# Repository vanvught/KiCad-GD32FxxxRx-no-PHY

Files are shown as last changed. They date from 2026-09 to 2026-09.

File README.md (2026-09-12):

[PayPal.Me Donate](https://paypal.me/AvanVught?locale.x=nl_NL)
-----------

# KiCad GD32F103R GD32F107R GD32F207R GD32F303R GD32F407R development board

This board can be used with the `GD32F103Rx`,  `GD32F303Rx` and the `GD32F107Rx` , `GD32F207Rx`, `GD32F407Rx` (Ethernet) MCU's. 

Please note that the crystal for the `GD32F107Rx`, `GD32F207Rx` and the `GD32F407Rx` is `25MHz` and the crystal for the `GD32F103Rx` and the  `GD32F303Rx` is `8MHz`.

The 2x13 header is pin compatible with the Orange Pi Zero and Raspberry Pi boards. 

Note: The BOM is for the GD32F407RE.
ToDo: Add information for other supported MCU's.

Details -> [https://www.gd32-dmx.org/dev-board.html](https://www.gd32-dmx.org/dev-board.html)

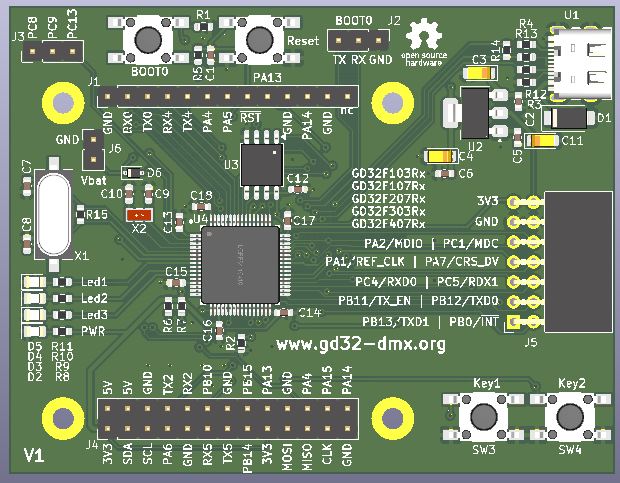
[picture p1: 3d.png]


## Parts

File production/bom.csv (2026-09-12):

Designator | Footprint | Quantity | Value | LCSC Part #
C1, C12, C13, C14, C15, C16, C17, C18, C2, C5, C6 | 0603 | 11 | 100n | C14663
C10, C9 | 0603 | 2 | 12pF | C38523
C11, C3, C4 | CP_EIA-3216-18_Kemet-A | 3 | 10uF | C7171
C7, C8 | 0603 | 2 | 20pF | C1648
D1 | D_SMA | 1 | SMAJ5.0A | C113952
D2, D3, D4, D5 | 0805 | 4 | LED | C2297
D6 | D_SOD-323 | 1 | 1N5819 | C48997863
R1, R2, R5 | 0603 | 3 | 10K | C25804
R10, R8, R9 | 0603 | 3 | 1K5 | C22975
R11 | 0603 | 1 | 1K5 | C22843
R12, R13 | 0603 | 2 | 22 | C23345
R15 | 0603 | 1 | 1M | C22935
R3, R4 | 0603 | 2 | 5K1 | C23186
R6, R7 | 0603 | 2 | 4K7 | C23162
SW1 | KEY-SMD_4P-L6.0-W6.0-P4.50-LS9.0 | 1 | BOOT0 | C221880
SW2 | KEY-SMD_4P-L6.0-W6.0-P4.50-LS9.0 | 1 | RESET | C221880
SW3 | KEY-SMD_4P-L6.0-W6.0-P4.50-LS9.0 | 1 | KEY1 | C221880
SW4 | KEY-SMD_4P-L6.0-W6.0-P4.50-LS9.0 | 1 | KEY2 | C221880
U1 | USB-C-SMD_G-SWITCH_GT-USB-7010ASV | 1 | GT-USB-7010ASV | C2988369
U2 | SOT-223-3_TabPin2 | 1 | AMS1117-3.3
U3 | SOIC-8_5.3x5.3mm_P1.27mm | 1 | W25Q128JVS | C97521
U4 | LQFP-64_L10.0-W10.0-P0.50-LS12.0-BL | 1 | GD32F407RET6 | C2688748
X1 | HC-49S_L11.4-W4.8 | 1 | 25Mhz | C14872
X2 | FC-135R_L3.2-W1.5 | 1 | 32.768kHz | C32346

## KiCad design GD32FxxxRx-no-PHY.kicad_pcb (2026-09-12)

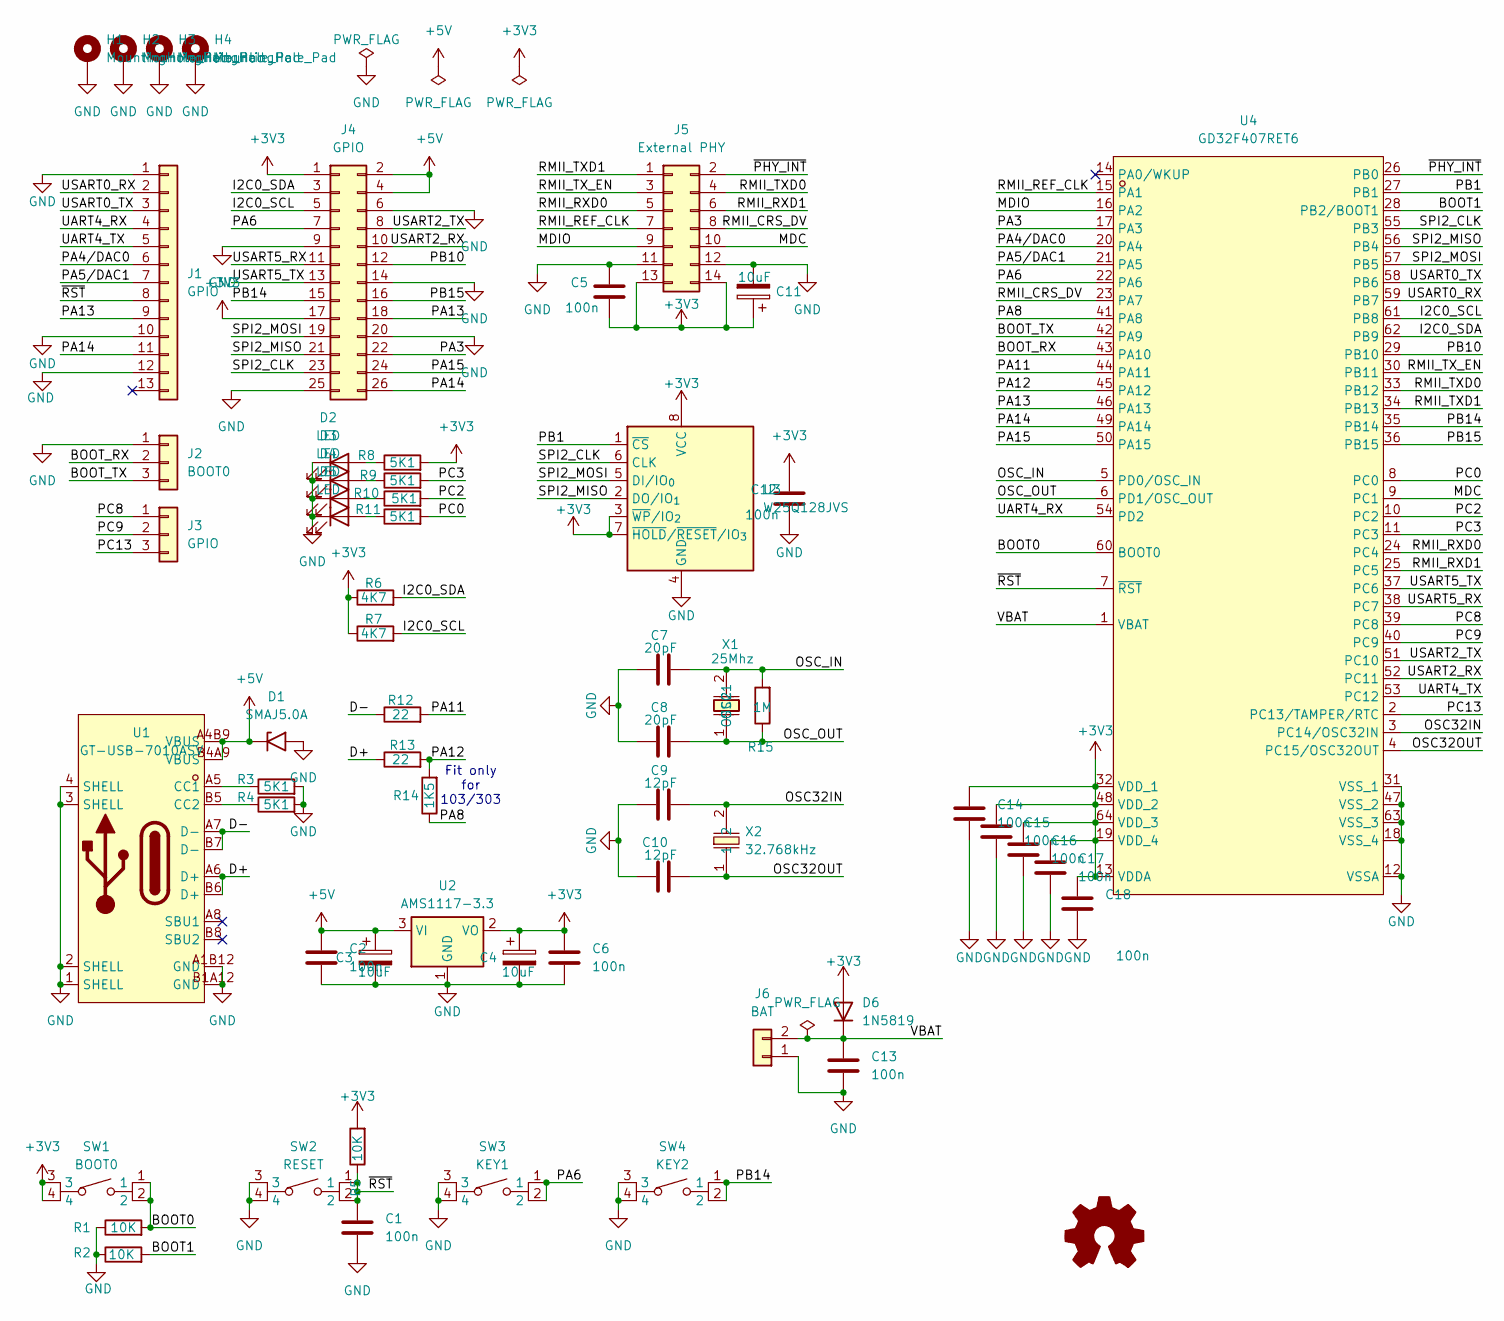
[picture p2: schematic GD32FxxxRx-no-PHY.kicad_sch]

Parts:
C1, C2, C5, C6, C12, C13, C14, C15, C16, C17, C18: 100n; C_0603_1608Metric; LCSC Part C14663
C3, C4, C11: 10uF; CP_EIA-3216-18_Kemet-A; LCSC Part C7171
C7, C8: 20pF; C_0603_1608Metric; LCSC Part C1648
C9, C10: 12pF; C_0603_1608Metric; LCSC Part C38523
D1: SMAJ5.0A; D_SMA; LCSC Part C113952
D2, D3, D4, D5: LED; LED_0805_2012Metric; LCSC Part C2297
D6: 1N5819; D_SOD-323; LCSC Part C48997863
H1, H2, H3, H4: MountingHole_Pad; MountingHole_2.7mm_M2.5_Pad
J1: GPIO; PinHeader_1x13_P2.54mm_Vertical
J2: BOOT0; PinHeader_1x03_P2.54mm_Vertical
J3: GPIO; PinHeader_1x03_P2.54mm_Vertical
J4: GPIO; PinHeader_2x13_P2.54mm_Vertical
J5: External PHY; PinSocket_2x07_P2.54mm_Horizontal
J6: BAT; PinHeader_1x02_P2.54mm_Vertical
R1, R2, R5: 10K; R_0603_1608Metric; LCSC Part C25804
R3, R4, R8, R9, R10, R11: 5K1; R_0603_1608Metric; LCSC Part C23186
R6, R7: 4K7; R_0603_1608Metric; LCSC Part C23162
R12, R13: 22; R_0603_1608Metric; LCSC Part C23345
R14: 1K5; R_0603_1608Metric; LCSC Part C22843
R15: 1M; R_0603_1608Metric; LCSC Part C22935
SW1: BOOT0; KEY-SMD_4P-L6.0-W6.0-P4.50-LS9.0; MPN PTS645SM43SMTR92LFS; LCSC Part C221880
SW2: RESET; KEY-SMD_4P-L6.0-W6.0-P4.50-LS9.0; MPN PTS645SM43SMTR92LFS; LCSC Part C221880
SW3: KEY1; KEY-SMD_4P-L6.0-W6.0-P4.50-LS9.0; MPN PTS645SM43SMTR92LFS; LCSC Part C221880
SW4: KEY2; KEY-SMD_4P-L6.0-W6.0-P4.50-LS9.0; MPN PTS645SM43SMTR92LFS; LCSC Part C221880
SYM1: Logo_Open_Hardware_Small; OSHW-Logo_5.7x6mm_SilkScreen
U1: GT-USB-7010ASV; USB-C-SMD_G-SWITCH_GT-USB-7010ASV; MPN GT-USB-7010ASV; LCSC Part C2988369
U2: AMS1117-3.3; SOT-223-3_TabPin2
U3: W25Q128JVS; SOIC-8_5.3x5.3mm_P1.27mm; LCSC Part C97521
U4: GD32F407RET6; LQFP-64_L10.0-W10.0-P0.50-LS12.0-BL; MPN GD32F407RET6; LCSC Part C2688748
X1: 25Mhz; HC-49S_L11.4-W4.8; MPN X49SM25MSD2SC; LCSC Part C14872
X2: 32.768kHz; FC-135R_L3.2-W1.5; MPN Q13FC13500004; LCSC Part C32346

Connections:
+3V3: C4.1, C5.2, C6.1, C11.1, C12.1, C14.1, C15.1, C16.1, C17.1, C18.1, D6.2 (A), J4.1, J4.17, J5.13, J5.14, R5.2, R6.1, R7.1, R8.2, SW1.3, SW1.4, U2.2 (VO), U3.3 (~WP/IO_{2}), U3.7 (~HOLD/~RESET/IO_{3}), U3.8 (VCC), U4.13 (VDDA), U4.19 (VDD_4), U4.32 (VDD_1), U4.48 (VDD_2), U4.64 (VDD_3)
+5V: C2.1, C3.1, D1.1 (A1), J4.2, J4.4, U1.A4B9 (VBUS), U1.B4A9 (VBUS), U2.3 (VI)
/BOOT0: R1.2, SW1.1, SW1.2, U4.60 (BOOT0)
/BOOT1: R2.2, U4.28 (PB2/BOOT1)
/BOOT_RX: J2.2, U4.43 (PA10)
/BOOT_TX: J2.3, U4.42 (PA9)
/D+: R13.1, U1.A6 (D+), U1.B6 (D+)
/D-: R12.1, U1.A7 (D-), U1.B7 (D-)
/I2C0_SCL: J4.5, R7.2, U4.61 (PB8)
/I2C0_SDA: J4.3, R6.2, U4.62 (PB9)
/MDC: J5.10, U4.9 (PC1)
/MDIO: J5.9, U4.16 (PA2)
/OSC32IN: C9.2, U4.3 (PC14/OSC32IN), X2.2
/OSC32OUT: C10.2, U4.4 (PC15/OSC32OUT), X2.1
/OSC_IN: C7.2, R15.2, U4.5 (PD0/OSC_IN), X1.2 (OSC2)
/OSC_OUT: C8.2, R15.1, U4.6 (PD1/OSC_OUT), X1.1 (OSC1)
/PA3: J4.22, U4.17 (PA3)
/PA4/DAC0: J1.6, U4.20 (PA4)
/PA5/DAC1: J1.7, U4.21 (PA5)
/PA6: J4.7, SW3.1, SW3.2, U4.22 (PA6)
/PA8: R14.1, U4.41 (PA8)
/PA11: R12.2, U4.44 (PA11)
/PA12: R13.2, R14.2, U4.45 (PA12)
/PA13: J1.9, J4.18, U4.46 (PA13)
/PA14: J1.11, J4.26, U4.49 (PA14)
/PA15: J4.24, U4.50 (PA15)
/PB1: U3.1 (~CS), U4.27 (PB1)
/PB10: J4.12, U4.29 (PB10)
/PB14: J4.15, SW4.1, SW4.2, U4.35 (PB14)
/PB15: J4.16, U4.36 (PB15)
/PC0: R11.2, U4.8 (PC0)
/PC2: R10.2, U4.10 (PC2)
/PC3: R9.2, U4.11 (PC3)
/PC8: J3.1, U4.39 (PC8)
/PC9: J3.2, U4.40 (PC9)
/PC13: J3.3, U4.2 (PC13/TAMPER/RTC)
/PHY_INT: J5.2, U4.26 (PB0)
/RMII_CRS_DV: J5.8, U4.23 (PA7)
/RMII_REF_CLK: J5.7, U4.15 (PA1)
/RMII_RXD0: J5.5, U4.24 (PC4)
/RMII_RXD1: J5.6, U4.25 (PC5)
/RMII_TXD0: J5.4, U4.33 (PB12)
/RMII_TXD1: J5.1, U4.34 (PB13)
/RMII_TX_EN: J5.3, U4.30 (PB11)
/SPI2_CLK: J4.23, U3.6 (CLK), U4.55 (PB3)
/SPI2_MISO: J4.21, U3.2 (DO/IO_{1}), U4.56 (PB4)
/SPI2_MOSI: J4.19, U3.5 (DI/IO_{0}), U4.57 (PB5)
/UART4_RX: J1.4, U4.54 (PD2)
/UART4_TX: J1.5, U4.53 (PC12)
/USART0_RX: J1.2, U4.59 (PB7)
/USART0_TX: J1.3, U4.58 (PB6)
/USART2_RX: J4.10, U4.52 (PC11)
/USART2_TX: J4.8, U4.51 (PC10)
/USART5_RX: J4.11, U4.38 (PC7)
/USART5_TX: J4.13, U4.37 (PC6)
/VBAT: C13.1, D6.1 (K), J6.2, U4.1 (VBAT)
/~RST: C1.1, J1.8, R5.1, SW2.1, SW2.2, U4.7 (~RST)
GND: C1.2, C2.2, C3.2, C4.2, C5.1, C6.2, C7.1, C8.1, C9.1, C10.1, C11.2, C12.2, C13.2, C14.2, C15.2, C16.2, C17.2, C18.2, D1.2 (A2), D2.1 (K), D3.1 (K), D4.1 (K), D5.1 (K), H1.1 (1_1), H2.1 (1_1), H3.1 (1_1), H4.1 (1_1), J1.1, J1.10, J1.12, J2.1, J4.6, J4.9, J4.14, J4.20, J4.25, J5.11, J5.12, J6.1, R1.1, R2.1, R3.2, R4.2, SW2.3, SW2.4, SW3.3, SW3.4, SW4.3, SW4.4, U1.1 (SHELL), U1.2 (SHELL), U1.3 (SHELL), U1.4 (SHELL), U1.A1B12 (GND), U1.B1A12 (GND), U2.1 (GND), U3.4 (GND), U4.12 (VSSA), U4.18 (VSS_4), U4.31 (VSS_1), U4.47 (VSS_2), U4.63 (VSS_3)
unnamed: D2.2 (A), R8.1
unnamed: D3.2 (A), R9.1
unnamed: D4.2 (A), R10.1
unnamed: D5.2 (A), R11.1
unnamed: R3.1, U1.A5 (CC1)
unnamed: R4.1, U1.B5 (CC2)

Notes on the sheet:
Fit only for 103/303

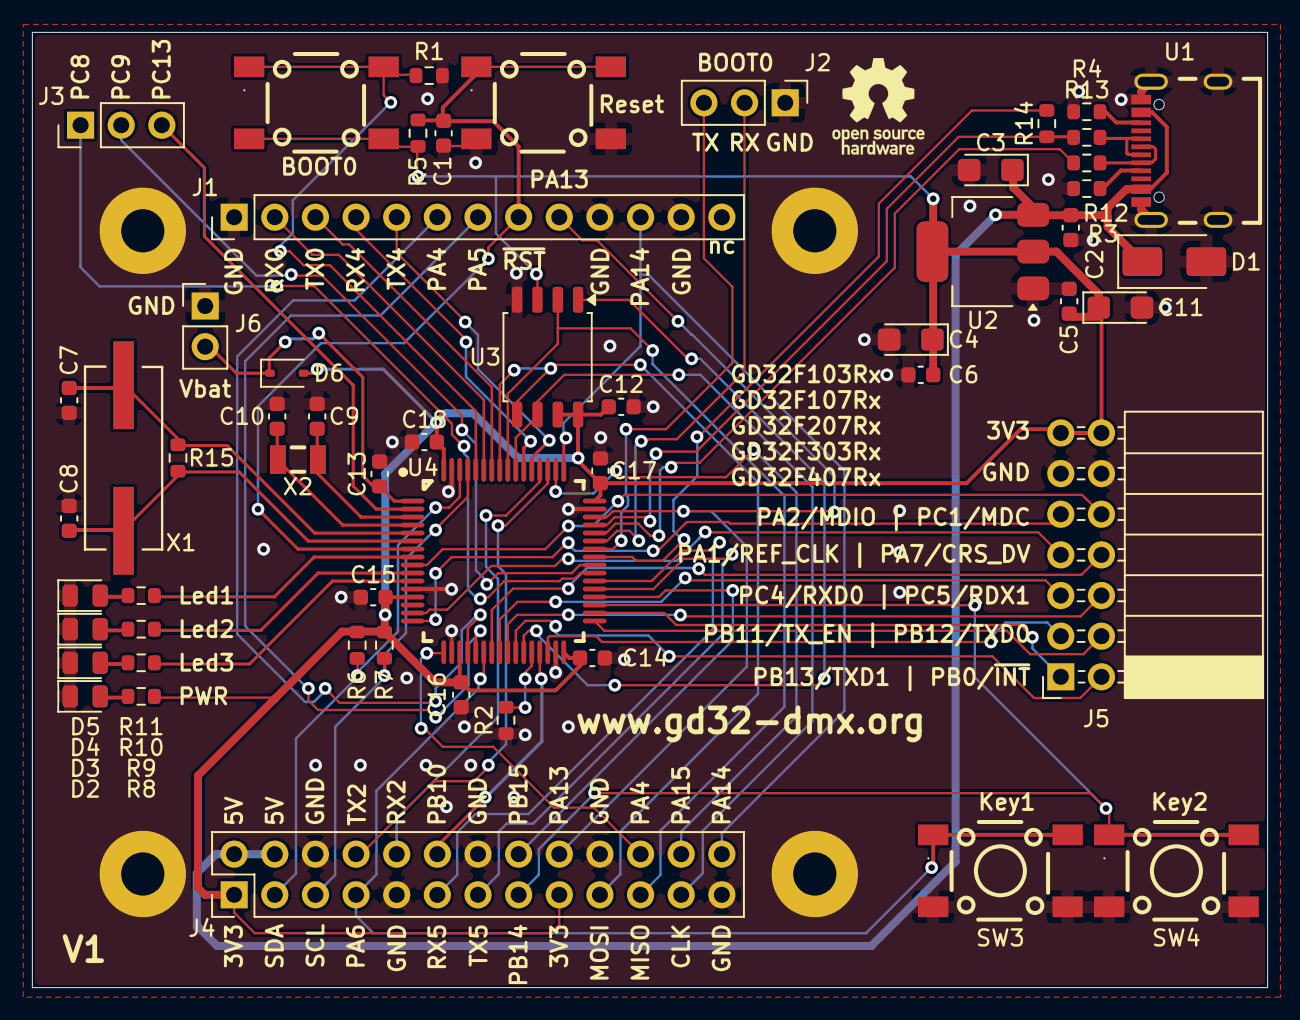
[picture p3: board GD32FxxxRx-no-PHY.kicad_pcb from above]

Board: 2 copper layers, 77.2 x 59.7 mm, 60 parts (0 on the bottom side), 64 nets.

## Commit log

2026-09-12 Add KiCad project and production CSV files
    Add the new `GD32FxxxRx-no-PHY.kicad_pro` project configuration and initial production outputs under `production/`: a BOM (`bom.csv`) and pick-and-place positions (`positions.csv`) for assembly/manuf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
    [bom.csv, positions.csv]
2026-09-12 Update README with board details
    Refresh the project README with a donation link, a clearer product title, and board support details for the GD32F103R, GD32F107R, GD32F207R, GD32F303R, and GD32F407R variants. This also documents the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
    [GD32FxxxRx-no-PHY.kicad_pcb, GD32FxxxRx-no-PHY.kicad_sch, designators.csv]
2026-09-12 Clarify BOM MCU target notes
    This commit updates the README to clarify that the BOM is for the GD32F407RE and adds a TODO to document support for the other supported MCUs.
